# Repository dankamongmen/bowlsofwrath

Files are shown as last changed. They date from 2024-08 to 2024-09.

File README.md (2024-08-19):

These bowls and struts are sized to snugly contain [4L cereal containers](https://www.amazon.com/gp/product/B0CFLJCJSF),
commonly employed as [dry boxen](https://www.thingiverse.com/thing:6254854) for
FDM filament spools. They furthermore embed a [Honeycomb wall](https://www.printables.com/model/152592-honeycomb-storage-wall)
into each side, into which the struts (and any other Honeycomb-compatible
item) are inserted. The front and back support several configurations,
depending on taste.

Neither supports nor small layer heights are necessary. A .2mm layer height 
with a 0.4mm nozzle is more than adequate. A .3mm layer height with a 0.6mm
nozzle ought likewise be fine. I typically print the struts using
polycarbonate, and everything else with ABS or ASA.

The honeycomb walls are oriented to support external hookups on both sides.

More info is available on [Dankwiki](https://nick-black.com/dankwiki/index.php/Dank%27s_Magnificent_Bowls).

## How do I use this?

These are [OpenSCAD](https://openscad.org/) source files. You'll want to
open them in OpenSCAD, adjust any parameters as needed, render them to
STL, and open that using the slicer of your choice. You'll need the
[BOSL2](https://github.com/BelfrySCAD/BOSL2) and
[roundedcube](https://danielupshaw.com/openscad-rounded-corners/) OpenSCAD
libraries.

You'll need at least one [Bowl](dankbowl.scad). For each Bowl you want to
connect, you'll need four [struts](struts.scad).

## Files

* [bolts.scad](bolts.scad): bolts for holding in placards on the front/back
* [dankbowl.scad](dankbowl.scad): the main Bowl
* [struts.scad](struts.scad): struts for connecting Bowls

**FIXME** add placards/wallpiece

## TODO

* Support internal hookups + slits to allow internal struts. Most of the
  honeycombs ought still be oriented to support external items.
* Restore honeycomb in floor, but make it optional. Ought be oriented to
    support external hookups. That would suggest you can't use these for
    internal struts, but you can: the bottom one will be held in by gravity.
* Make unified "wall" placard that covers both halves.
* Adjust existing placards to accommodate internal chamfers.
* New placard for 30256 label.
* New placard for--you guessed it--honeycomb.
* Parameterize struts.
* Struts that connect horizontally in addition to vertically.
* Snap-in bolts.
* 3MF project files.

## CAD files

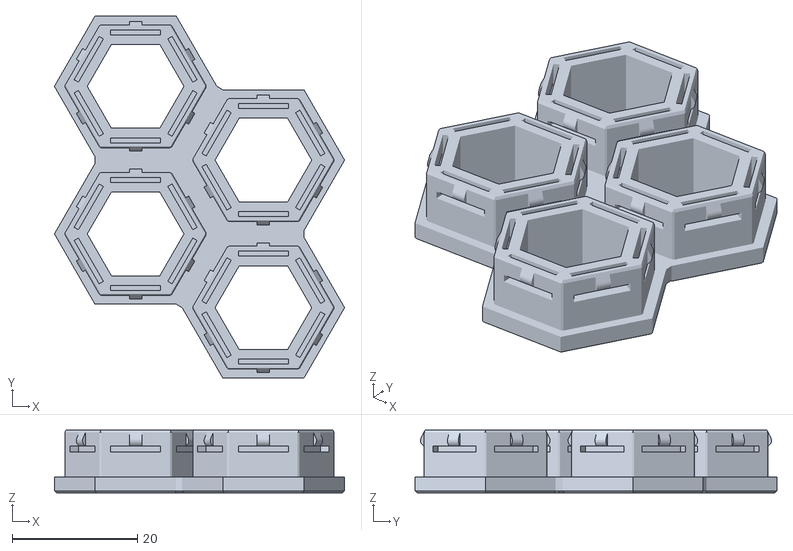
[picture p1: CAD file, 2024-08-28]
insert-hollow-for.stl
46.4 x 57.9 x 10.0

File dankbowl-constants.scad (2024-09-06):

include <BOSL2/std.scad>
include <BOSL2/screws.scad>
include <roundedcube.scad>
include <hex.scad>
// common constants used across multiple files

$fa = 6;
//$fs = 1.75 / 2;
$fn = 32;

// a carton is 222mm long where it intersects with the bolt.
// two next to one another are 204mm wide with a ~20mm clearance.
// a carton is 250mm tall.

module multicolor(color) {
	if (current_color != "ALL" && current_color != color) { 
			// ignore our children.
			// (I originally used "scale([0,0,0])" which also works but isn't needed.) 
	} else {
			color(color)
			children();
	}        
}

boltd = 5;
mainx = 204;
mainy = 76;
mainz = 216;

towerd = 20;
towerw = 18;

rwallr = 8; // same thickness as honeycomb

fpanelx = (mainx - towerw) / 2 - 1; // give it a mm of squish room
fpanely = mainy - 1; // same deal, one mm of squish
fpanelz = 8;

height = 20;
wall = 1.8;

mtotx = mainx + rwallr * 2;
mtoty = mainy + rwallr;
mtotz = mainz + rwallr * 2;

// interaction between fpanels and extremal side of bowls:
// can be magnets and/or rotating, sliding slug.
// cutaway for 20x5x2mm bar magnet--triangle on top to avoid need for supports
magneth = 20;
magnetw = 5;
magnetd = 3; // give away 1mm
// support is a boolean specifying whether there ought be a triangle
// at the top to eliminate the need for supports; only useful when
// the holes are to be oriented vertically
module maghole(y, support){
	translate([0, y, 0]){
		cube([magnetd, magneth, magnetw]);
		if(support){
			translate([0, 0, magnetw]){
				rotate([0, 90, 0]){
					linear_extrude(magnetd){
						polygon([[0, magneth], [magnetw / 2, magneth + magnetw / 2], [magnetw, magneth]]);
					}
				}
			}
		}
	}
}

module magholes(support){
	for(i = [rwallr + 5:magneth * 1.5:fpanely - rwallr]){
		maghole(i, support);
	}
}

// it needs to cross the full wall of the bowl, and leave room
// on the placard to easily manipulate it.
boltlength = rwallr * 4;
boltlatchw = 2;
sluglength = rwallr * 3;

module boltpath(){
	// first the bottom
	screw_hole("M5", length=mtotx*3, thread=false, orient=LEFT);
	// now the top
	translate([0, mainy - 10, 0]){
		screw_hole("M5", length=mtotx*3, thread=false, orient=LEFT);
	}
}

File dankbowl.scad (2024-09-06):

include <fpanel.scad>

// 0.1.1 -- reconnected two parts of towers
// 0.1.0 -- no functional changes
// 0.0.997 -- perfect rounding on interior
// 0.0.996 -- fermilab style sides on towers
//            switch to bar magnets
// 0.0.995 -- added cutaways for magnets
//            boxed off back of towers
// 0.0.992 -- reduced height by 4mm
//            fixed up some minor manifold faults
//            honeycomb bottom is mandatory
// 0.0.991 -- lined up througholes better
//            added optional honeycomb bottom
//            moved out holes for 2mm more length
// 0.0.99 -- external rounding only with "y" to properly hold combs
// 0.0.98 -- properly oriented side honeycomb for external latching

current_color = "ALL";

module lfill(xoffbase){
	polygon([[xoffbase, -33.5],
				 [xoffbase, -29 + htotx],
				 [xoffbase + htotx / 2 + 0.5, -28 + 2 * htotx / 3],
				 [xoffbase + htotx / 2 + 0.5, -35 + htotx / 3]]);
}

module bfill(x){
	polygon([[-33, x],
				 [-29 + htotx, x],
				 [-28 + 2 * htotx / 3, x + htotx / 2 + 0.5],
				 [-35 + htotx / 3, x + htotx / 2 + 0.5]]);
}

//hexh = 5.77349; // 10**2 + x**2 = 11.547**2
hexh = 7.5;
hexy = 26.5;
lex = 8;
htotx = height + 2 * wall - 0.05; // FIXME eliminate

// the sidecomb ought be mtoty - rwallr * 2 tall,
// mtotz - rwallr * 2 long, and rwallr deep.
module sidecomb(){
	xoffbase = -100.2; // FIXME eliminate
	translate([0, mtoty / 2 + rwallr, mtotz / 2]){
		rotate([0, 90, 0]){
			intersection(){
				union(){
					hexwall(8, 3);
					// fill in the top holes (on the left side, bottom on right)
					for(i = [0:1:7]){
						linear_extrude(lex){
							polygon([[xoffbase + i * htotx, hexy + hexh],
											 [xoffbase + i * htotx + 11.8, hexy],
											 [xoffbase + i * htotx + 23.6, hexy + hexh]]);
							polygon([[xoffbase + i * htotx, -hexy - hexh],
											 [xoffbase + i * htotx + 11.8, -hexy],
											 [xoffbase + i * htotx + 23.6, -hexy - hexh]]);
						}
					}
					linear_extrude(lex){
						polygon([[xoffbase + 8 * htotx, 34],
										 [xoffbase + 8 * htotx + wall + height / 2, 27],
										 [xoffbase + 8 * htotx + wall + height / 2, 34]]);
						polygon([[xoffbase + 8 * htotx, -34],
										 [xoffbase + 8 * htotx + wall + height / 2, -27],
										 [xoffbase + 8 * htotx + wall + height / 2, -34]]);
						// fill in the front holes on both sides
						translate([0, -1, 0]){
							lfill(xoffbase);
						}
						translate([0, height * 2, 0]){
							lfill(xoffbase);
						}
						// fill in the back hole on both sides
						translate([0, height - 0.75, 0]){
							mirror([1, 0, 0]){
								lfill(xoffbase);
							}
						}
					}
					// fill in the remaining front
					translate([mtotz / 2 - rwallr * 2, -mtoty / 2 + rwallr, 0]){
						cube([rwallr, mtoty - rwallr * 2, rwallr]);
					}
					// fill in the remaining back
					translate([-mtotz / 2 + rwallr, -mtoty / 2 + rwallr, 0]){
						cube([rwallr, mtoty - rwallr * 2, rwallr]);
					}
				} // end union
				// should fill this space:
				translate([0, 0, rwallr / 2]){
					cube([mtotz - rwallr * 2, mtoty - rwallr * 2, rwallr], true);
				}
			} // end intersection
		} // end rotate
	} // end translate
}

module bottom(){
	intersection(){
		// want to line up with the middle rows on the sides
		translate([mtotx / 2, 0, mtotz / 2]){
			rotate([0, 90, 0]){
				rotate([270, 0, 0]){
					hexwall(7, 9);
					// fill in front and back
					for(i = [0:1:4]){
						translate([-88, 40.8 * i - 81.5, 0]){
							rotate([0, 0, 90]){
								cylinder(lex, 14, 14, $fn = 6);
							}
						}
					}
					for(i = [0:1:3]){
						translate([88, 40.8 * i - 61, 0]){
							rotate([0, 0, 90]){
								cylinder(lex, 14, 14, $fn = 6);
							}
						}
					}
					// fill in left and right
					for(i = [0:1:7]){
						translate([23.5 * i - 76, -mainx / 2, 0]){
							rotate([0, 0, 90]){
								cylinder(lex, 14, 14, $fn = 6);
							}
						}
						translate([23.5 * i - 76, mainx / 2, 0]){
							rotate([0, 0, 90]){
								cylinder(lex, 14, 14, $fn = 6);
							}
						}
					}
				}
			}
		}
		// remove anything leaking over the sides
		translate([rwallr, 0, rwallr]){
			cube([mtotx - rwallr * 2, lex, mtotz - rwallr * 2]);
		}
	}
}

module magholepair(){
	translate([0, 0, (fpanelz - magnetw) / 2]){
		magholes();
	}
	translate([0, 0, mtotz - magnetw - (fpanelz - magnetw) / 2]){
		magholes();
	}
}

module tower(){
	// tower in front/back centers for bolts
	// we have about 20mm of gap between the two boxes
	difference(){
		union(){
			rotate([0, 90, 0]){
				// triangle support for tower
				translate([0, 0, rwallr / 2]){
					linear_extrude(towerw - rwallr){
							polygon([
								[towerd / 2, 0],
								[towerd / 2, mainy - rwallr / 2],
								[towerd, 0]
							]);
					}
					translate([rwallr, 0, 0]){
						cube([2, mainy - rwallr / 2, towerw - rwallr]);
					}
				}
				roundedcube([towerd - rwallr * 2, mainy, towerw], false, rwallr / 2, "xmin");
			}
			// restore full bottom
			translate([-rwallr, 0, (-towerd - rwallr) / 2]){
				difference(){
					cube([towerw + rwallr * 2, 9, towerd / 2 + rwallr]);
					translate([0, rwallr, 0]){
						linear_extrude(towerd / 2 + rwallr){
							circle(rwallr);
							translate([towerw + rwallr * 2, 0, 0]){
								circle(rwallr);
							}
						}
					}
				}
			}
		}
		// top hole
		translate([towerw / 2, mainy - 5, 0]){
			screw_hole("M5", length=towerw + rwallr * 2, thread=true, orient=LEFT);
		}
		// bottom hole
		translate([towerw / 2, 5, 0]){
			screw_hole("M5", length=towerw + rwallr * 2, thread=true, orient=LEFT);
		}
		translate([0, 0, -fpanelz / 2]){
			magholepair();
			translate([towerw - magnetd, 0, 0]){
				magholepair();
			}
		}
	}
}

// rotate the entirety to sit on the plate naturally
rotate([90, 0, 0]){
	difference(){
		union(){
			difference(){
				// the primary bowl
				roundedcube([mtotx, mtoty, mtotz], false, rwallr, "ymin");
				// remove the bottom
				translate([rwallr * 2, 0, towerd + 8]){
					cube([mtotx - rwallr * 4, rwallr, mtotz - towerd * 2 - 16]);
				}
				// remove the sides to insert the honeycomb
				translate([0, rwallr * 2, rwallr]){
					cube([mtotx, mtoty - rwallr * 2, mtotz - rwallr * 2]);
				}
				// passageways for bolts (front then back)
				translate([0, rwallr + 5, mtotz - fpanelz / 2]){
					boltpath();
				}
				translate([0, rwallr + 5, fpanelz / 2]){
					boltpath();
				}
				translate([rwallr - magnetd + 0.1, rwallr, 0]){
					magholepair();
				}
				translate([mtotx - rwallr - 0.1, rwallr, 0]){
					magholepair();
				}
				translate([mtotx - 20, 7, mtotz - 10]){
					rotate([90, 0, 180]){
						linear_extrude(2){
							text("v0.1.1 2024-08-31", size=5);
						}
					}
				}
			}

			multicolor("green"){
				// left side. don't translate -- the hole ought come to meet us
				// (thus requiring less translation for the other side).
				sidecomb();
			}
			
			multicolor("pink"){
				// right side
				translate([mtotx, mtoty + rwallr * 2, 0]){
					rotate([180, 180, 0]){
						sidecomb();
					}
				}
			}
			
			multicolor("white"){
				bottom();
			}
		}
		// remove the core, leaving filleted inside
		translate([(mtotx - mainx) / 2, rwallr * 2, -rwallr]){
			cube([mainx, mtoty - rwallr * 2, mtotz + 2 * rwallr]);
			translate([rwallr, -rwallr, 0]){
				cube([mainx - rwallr * 2, rwallr, mtotz + 2 * rwallr]);
			}
		}
		translate([rwallr * 2, rwallr * 2, 0]){
			linear_extrude(mtotz){
				circle(rwallr);
			}
		}
		translate([mtotx - rwallr * 2, rwallr * 2, 0]){
			linear_extrude(mtotz){
				circle(rwallr);
			}
		}
	}	// end difference

	multicolor("blue"){
		// tower in the front
		translate([mtotx / 2 - towerw / 2, 8, mtotz - rwallr / 2]){
			tower();
		}
		// tower in the back (aligned to x axis)
		translate([mtotx / 2 - towerw / 2, 8, rwallr / 2]){
			mirror([0, 0, 1]){
				tower();
			}
		}
	} // blue

	// for testing
	multicolor("red"){
		/*translate([0, rwallr + 5, mtotz - fpanelz / 2]){
			boltpath();
		}
		translate([0, rwallr + 5, fpanelz / 2]){
			boltpath();
		}
		translate([0, 30, 27.2]){
			rotate([30, 0, 0]){
				rotate([0, 90, 0]){
					linear_extrude(mtotx){
						circle(13.6, $fn=6);
					}
				}
			}
		}*/
	}
} // end rotation

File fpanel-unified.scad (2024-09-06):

include <fpanel.scad>

//current_color="ALL";
current_color="black";
//current_color="white";

fpanel("polyc");

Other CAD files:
fpanel.scad
hex.scad
struts.scad
trashcan.scad

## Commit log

2024-08-17 import struts and bowl from old repo
    [dankbowl-constants.scad, dankbowl.scad, struts.scad]
2024-08-17 we want snap-in bolts
2024-08-17 add minimized hex.scad
    [dankbowl-constants.scad, hex.scad]
2024-08-19 don't round the sides
    [dankbowl.scad]
2024-08-19 README.md: list files
    [bolts.scad]
2024-08-19 README.md: material advice
2024-08-19 dankbowl: implement optional honeycomb bottom
    [dankbowl.scad]
2024-08-19 tighten up extrusion to match roundedcube
    [dankbowl-constants.scad, dankbowl.scad]
2024-08-19 expand length for spool by 2mm, one on each side
    [dankbowl.scad]
2024-08-19 dankbowl: rotate into the xy plane for easy printing
    [dankbowl.scad]
2024-08-21 use common constants for bolts
    [bolts.scad]
2024-08-21 dankbowl: cut 4mm out from height
    [dankbowl-constants.scad, dankbowl.scad]
2024-08-21 try m5 bolts
    [bolts.scad]
2024-08-21 turn off testing rods
    [dankbowl.scad]
2024-08-21 Makefile: generate bolts.stl
2024-08-21 adjust wall excision to match reduced height
    [dankbowl.scad]
2024-08-21 close tiny manifold faults
    [dankbowl.scad]
2024-08-21 text on both sides of placard
    [fpanel.scad]
2024-08-21 dankbowl: smooth out top of bottom
    [dankbowl.scad]
2024-08-21 line up placard holes
    [dankbowl.scad, fpanel.scad]
2024-08-21 round placards
    [dankbowl.scad, fpanel.scad]
2024-08-22 put all bolts on the xy plane
    [bolts.scad]
2024-08-23 remove bolts definition
    [bolts.scad, dankbowl-constants.scad, fpanel.scad]
2024-08-23 fpanel: move back text over a few pixels for TPU
    [fpanel.scad]
2024-08-23 revolutionary new fpanel sans bolts
    [dankbowl-constants.scad, fpanel.scad]
2024-08-23 fpanel: add holes for 5x3mm magnets
    [dankbowl-constants.scad, fpanel.scad]
2024-08-24 0.0.996: move to bar magnets, fermi up the towers
    [dankbowl-constants.scad, dankbowl.scad, fpanel.scad]
2024-08-26 perfect interior rounding, round exterior corners
    [dankbowl.scad, fpanel.scad]
2024-08-26 try out github's embedded stl viewer
2024-08-26 drop STL from readme
2024-08-28 kill extrusion fudge factor
    [dankbowl.scad]
2024-08-28 remove unused constants
    [dankbowl-constants.scad, dankbowl.scad]
2024-08-28 kill weird subtractions by redefining mainz
    [dankbowl-constants.scad, dankbowl.scad]
2024-08-28 simplify bottom calculations
    [dankbowl.scad, fpanel-unified.scad]
2024-08-28 inroll on two corners of fpanel
    [fpanel.scad]
2024-08-28 kill wall{x, y, z} constants
    [dankbowl-constants.scad, dankbowl.scad]
2024-08-28 kill unused bard constant
    [dankbowl-constants.scad]
2024-08-28 widen hull of strut
    [dankbowl-constants.scad, struts.scad]
2024-08-28 move inserts to top of trashcan
    [insert-hollow-for.stl, trashcan.scad]
2024-08-28 v0.1.0, yay!
    [dankbowl.scad]
2024-09-06 v0.1.1 -- reconnect disconnected towers
    [dankbowl-constants.scad, dankbowl.scad, fpanel-unified.scad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]
2024-09-22 fpanel: drop roundedcube include
    [fpanel.scad]
